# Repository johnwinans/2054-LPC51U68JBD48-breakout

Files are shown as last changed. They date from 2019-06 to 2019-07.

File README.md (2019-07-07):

# 2054-LPC51U68JBD48-breakout
LPC51U68JBD48 Breakout Board

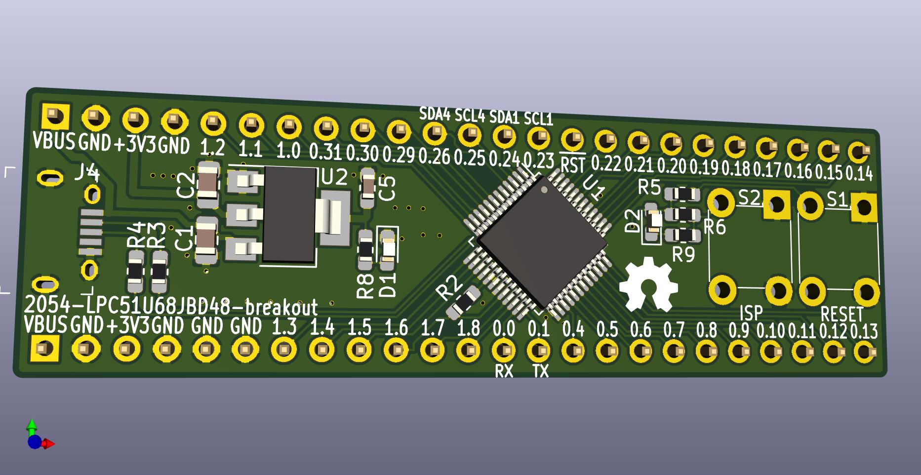
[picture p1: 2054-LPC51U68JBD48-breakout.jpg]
Front


Oops... I put the wrong URL on the Rev-1 release tag.  You can order Rev 1 of this board from OSH Park here: https://oshpark.com/shared_projects/a4fI5XNS (I receive no commission.)

Double-oops, there is no soldermask threaded between the pins of U1 in Rev-1.  This flaw is not a show-stopper.  It would have been nice to have.  

This has been fixed by reducing the solder mask expansion in Rev 1.1 to 1.8 mils.

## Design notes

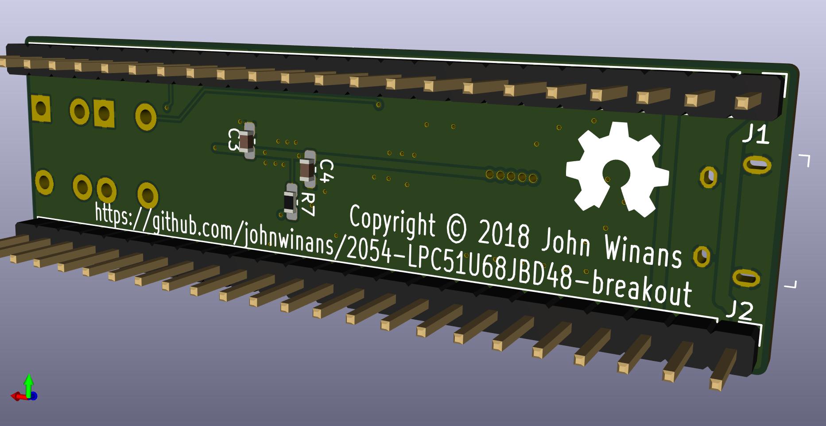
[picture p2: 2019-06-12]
2054-LPC51U68JBD48-breakout-back.jpg

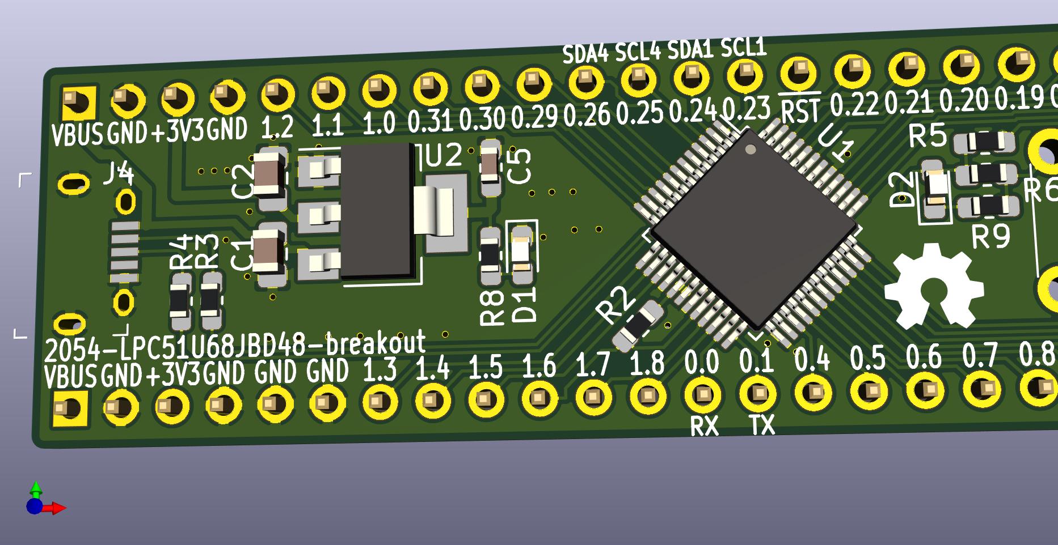
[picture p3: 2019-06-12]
2054-LPC51U68JBD48-breakout-back-front.jpg

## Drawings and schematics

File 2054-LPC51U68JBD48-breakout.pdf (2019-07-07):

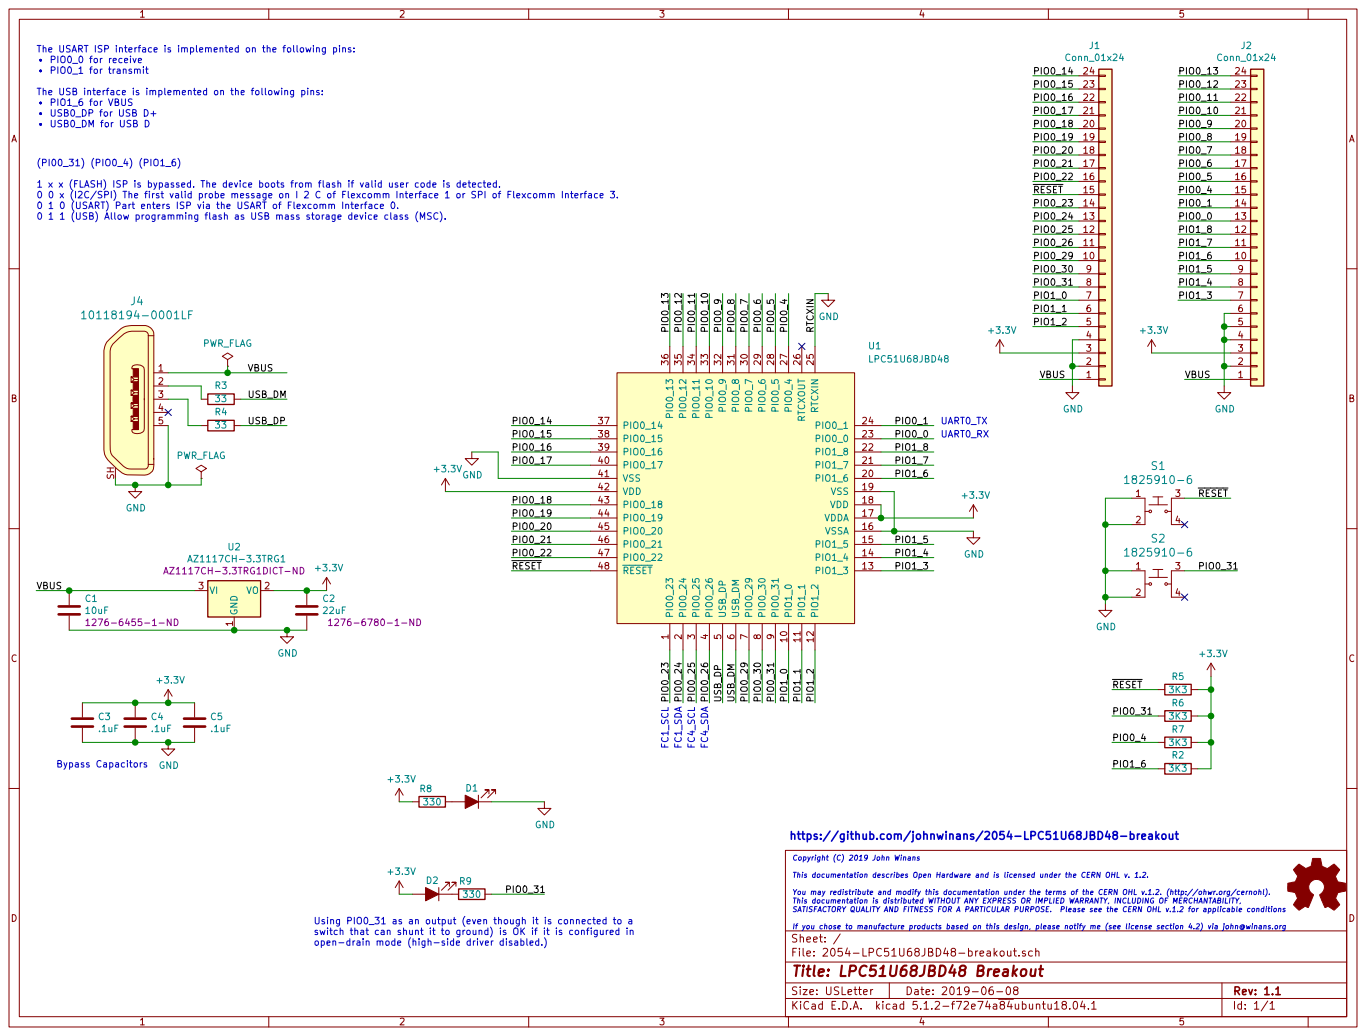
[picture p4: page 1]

The USART ISP interface is implemented on the following pins:
PIO0_0 for receive
PIO0_1 for transmit The USB interface is implemented on the following pins:

1 x x (FLASH) ISP is bypassed. The device boots from flash if valid user code is detected.
0 0 x (I2C/SPI) The first valid probe message on I 2 C of Flexcomm Interface 1 or SPI of Flexcomm Interface 3.
0 1 0 (USART) Part enters ISP via the USART of Flexcomm Interface 0.

1 PIO1_0 10 PIO1_1 11 PIO1_2 12 PIO1_3 13 PIO1_4 14 PIO1_5 15 VSSA 16 VDDA 17 VDD 18 VSS 19 PIO0_24

Copyright (C) 2019 John Winans This documentation describes Open Hardware and is licensed under the CERN OHL v. 1.2. You may redistribute and modify this documentation under the terms of the CERN OHL v.1.2. (http://ohwr.org/cernohl). This documentation is distributed WITHOUT ANY EXPRESS OR IMPLIED WARRANTY, INCLUDING OF MERCHANTABILITY, SATISFACTORY QUALITY AND FITNESS FOR A PARTICULAR PURPOSE. Please see the CERN OHL v.1.2 for applicable conditions

PIO0_31 Using PIO0_31 as an output (even though it is connected to a

If you chose to manufacture products based on this design, please notify me (see license section 4.2) via john@winans.org

switch that can shunt it to ground) is OK if it is configured in

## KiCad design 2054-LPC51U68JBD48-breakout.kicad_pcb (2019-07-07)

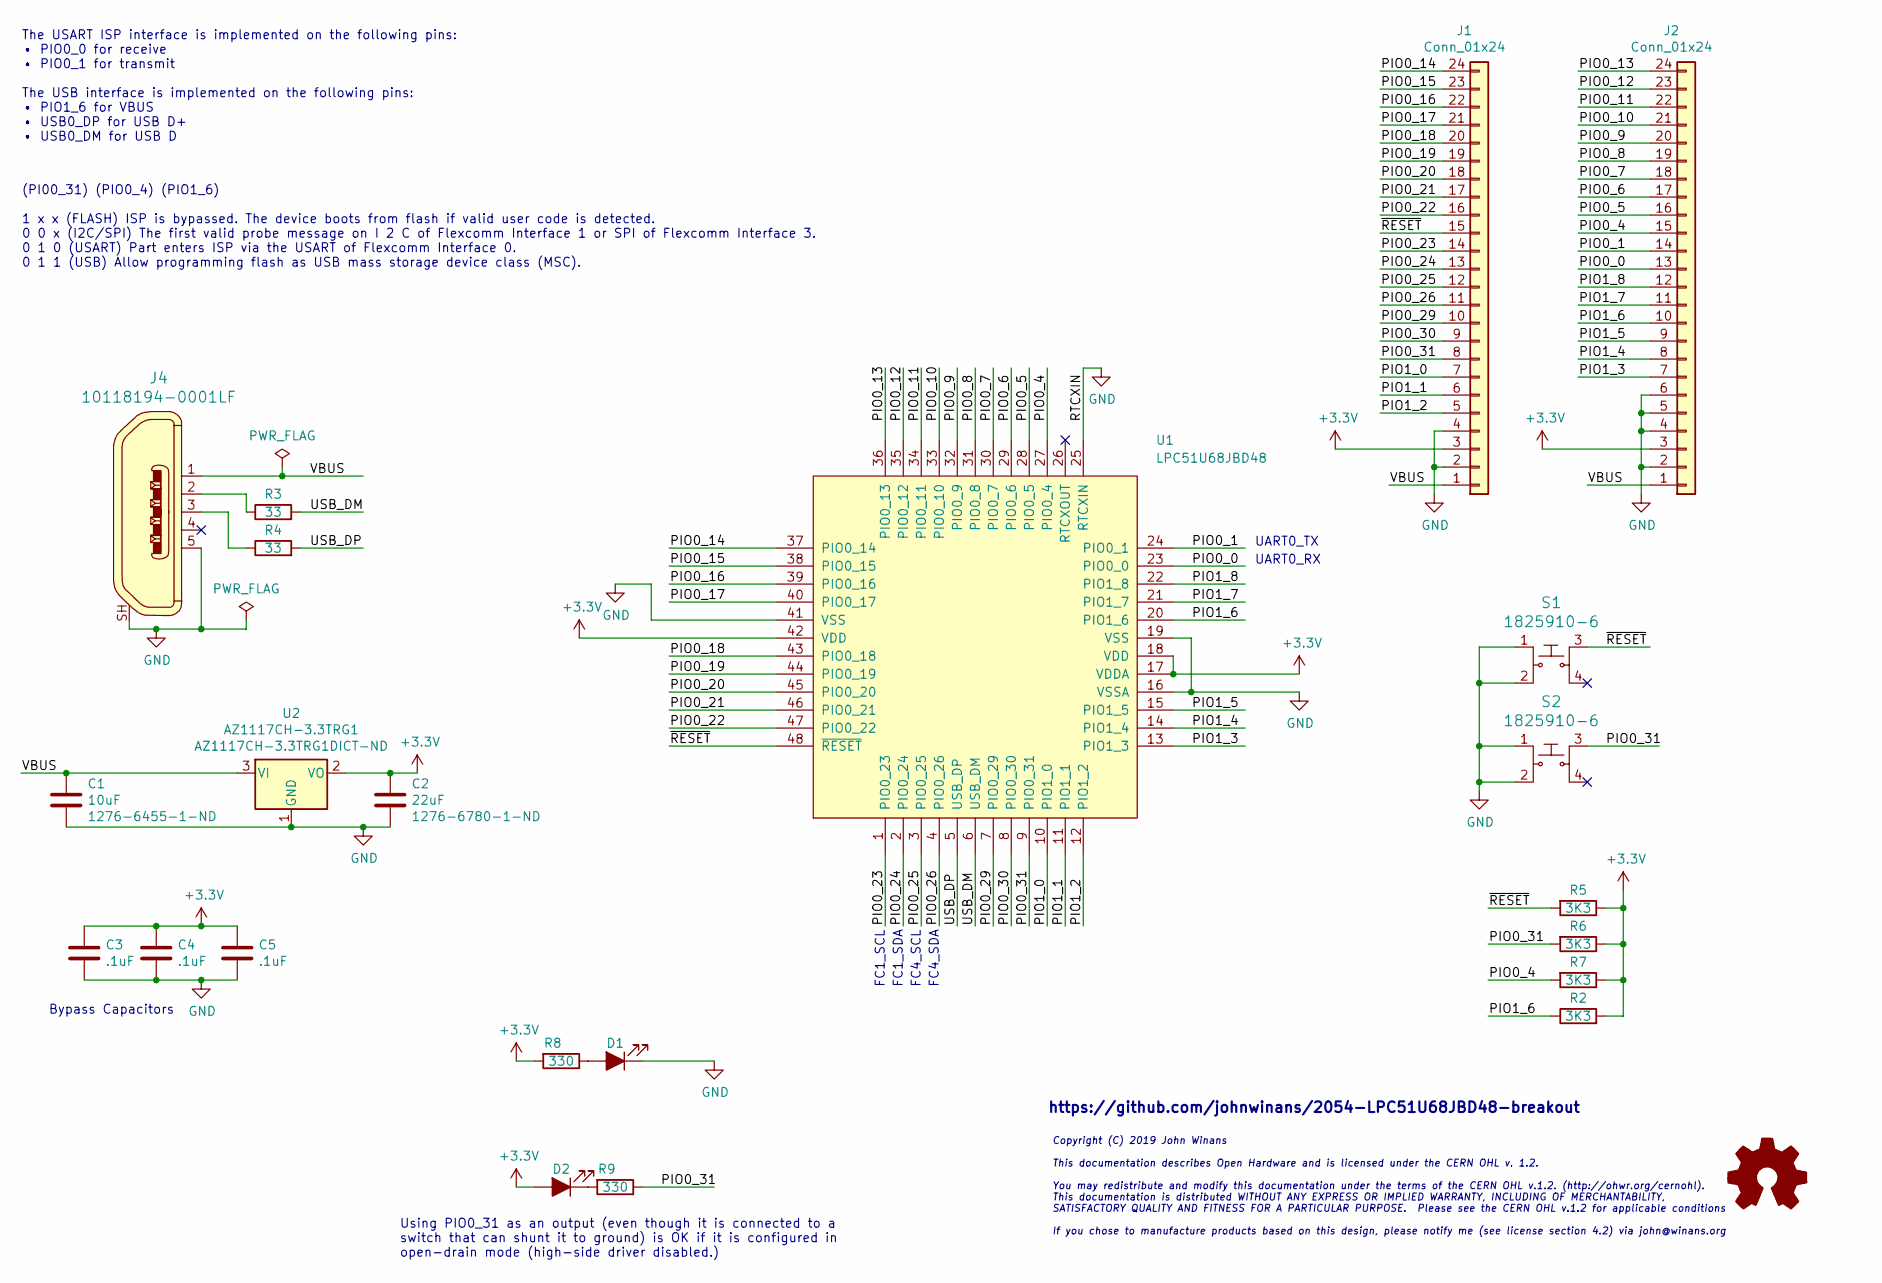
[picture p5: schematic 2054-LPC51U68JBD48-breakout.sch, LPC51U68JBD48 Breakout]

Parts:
C1: 10uF; C_0805_2012Metric_Pad1.15x1.40mm_HandSolder; digikey 1276-6455-1-ND
C2: 22uF; C_0805_2012Metric_Pad1.15x1.40mm_HandSolder; digikey 1276-6780-1-ND
C3, C4, C5: .1uF; C_0603_1608Metric_Pad1.05x0.95mm_HandSolder; digikey.com 445-6854-1-ND
D1, D2: LED_ALT; LED_0603_1608Metric_Pad1.05x0.95mm_HandSolder
J1, J2: Conn_01x24; PinHeader_1x24_P2.54mm_Vertical
J4: 10118194-0001LF; USB_Micro_B_Female_10118194-0001LF; MPN 10118194-0001LF; Digi-Key_PN 609-4618-1-ND
LOGO1: Logo_Open_Hardware_Small; OSHW-Symbol_6.7x6mm_SilkScreen
R2, R5, R6, R7: 3K3; R_0603_1608Metric_Pad1.05x0.95mm_HandSolder; digikey.com 311-100HRCT-ND
R3, R4: 33; R_0603_1608Metric_Pad1.05x0.95mm_HandSolder; digikey.com 311-100HRCT-ND
R8, R9: 330; R_0603_1608Metric_Pad1.05x0.95mm_HandSolder; digikey.com 311-1.00KHRCT-ND
S1, S2: 1825910-6; Switch_Tactile_THT_6x6mm; MPN 1825910-6; Digi-Key_PN 450-1650-ND
U1: LPC51U68JBD48; LQFP-48_7x7mm_P0.5mm
U2: AZ1117CH-3.3TRG1; SOT-223-3_TabPin2; digikey AZ1117CH-3.3TRG1DICT-ND

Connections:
+3V3: C2.1, C3.1, C4.1, C5.1, D2.2 (A), J1.3, J2.3, R2.2, R5.1, R6.1, R7.1, R8.2, U1.17 (VDDA), U1.18 (VDD), U1.42 (VDD), U2.2 (VO)
/PIO0_0: J2.13, U1.23 (PIO0_0)
/PIO0_1: J2.14, U1.24 (PIO0_1)
/PIO0_4: J2.15, R7.2, U1.27 (PIO0_4)
/PIO0_5: J2.16, U1.28 (PIO0_5)
/PIO0_6: J2.17, U1.29 (PIO0_6)
/PIO0_7: J2.18, U1.30 (PIO0_7)
/PIO0_8: J2.19, U1.31 (PIO0_8)
/PIO0_9: J2.20, U1.32 (PIO0_9)
/PIO0_10: J2.21, U1.33 (PIO0_10)
/PIO0_11: J2.22, U1.34 (PIO0_11)
/PIO0_12: J2.23, U1.35 (PIO0_12)
/PIO0_13: J2.24, U1.36 (PIO0_13)
/PIO0_14: J1.24, U1.37 (PIO0_14)
/PIO0_15: J1.23, U1.38 (PIO0_15)
/PIO0_16: J1.22, U1.39 (PIO0_16)
/PIO0_17: J1.21, U1.40 (PIO0_17)
/PIO0_18: J1.20, U1.43 (PIO0_18)
/PIO0_19: J1.19, U1.44 (PIO0_19)
/PIO0_20: J1.18, U1.45 (PIO0_20)
/PIO0_21: J1.17, U1.46 (PIO0_21)
/PIO0_22: J1.16, U1.47 (PIO0_22)
/PIO0_23: J1.14, U1.1 (PIO0_23)
/PIO0_24: J1.13, U1.2 (PIO0_24)
/PIO0_25: J1.12, U1.3 (PIO0_25)
/PIO0_26: J1.11, U1.4 (PIO0_26)
/PIO0_29: J1.10, U1.7 (PIO0_29)
/PIO0_30: J1.9, U1.8 (PIO0_30)
/PIO0_31: J1.8, R6.2, R9.1, S2.3, U1.9 (PIO0_31)
/PIO1_0: J1.7, U1.10 (PIO1_0)
/PIO1_1: J1.6, U1.11 (PIO1_1)
/PIO1_2: J1.5, U1.12 (PIO1_2)
/PIO1_3: J2.7, U1.13 (PIO1_3)
/PIO1_4: J2.8, U1.14 (PIO1_4)
/PIO1_5: J2.9, U1.15 (PIO1_5)
/PIO1_6: J2.10, R2.1, U1.20 (PIO1_6)
/PIO1_7: J2.11, U1.21 (PIO1_7)
/PIO1_8: J2.12, U1.22 (PIO1_8)
/USB_DM: R3.2, U1.6 (USB_DM)
/USB_DP: R4.2, U1.5 (USB_DP)
/VBUS: C1.1, J1.1, J2.1, J4.1, U2.3 (VI)
/~RESET~: J1.15, R5.2, S1.3, U1.48 (~RESET~)
GND: C1.2, C2.2, C3.2, C4.2, C5.2, D1.1 (K), J1.2, J1.4, J2.2, J2.4, J2.5, J2.6, J4.5, J4.SH, S1.1, S1.2, S2.1, S2.2, U1.16 (VSSA), U1.19 (VSS), U1.25 (RTCXIN), U1.41 (VSS), U2.1 (GND)
unnamed: D1.2 (A), R8.1
unnamed: D2.1 (K), R9.2
unnamed: J4.2, R3.1
unnamed: J4.3, R4.1

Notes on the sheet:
Bypass Capacitors
Copyright (C) 2019 John Winans This documentation describes Open Hardware and is licensed under the CERN OHL v. 1.2. You may redistribute and modify this documentation under the terms of the CERN OHL v.1.2. (http://ohwr.org/cernohl). This documentation is distributed WITHOUT ANY EXPRESS OR IMPLIED 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
The USART ISP interface is implemented on the following pins: • PIO0_0 for receive • PIO0_1 for transmit The USB interface is implemented on the following pins: • PIO1_6 for VBUS • USB0_DP for USB D+ • USB0_DM for USB D
(PI00_31) (PIO0_4) (PIO1_6) 1 x x (FLASH) ISP is bypassed. The device boots from flash if valid user code is detected. 0 0 x (I2C/SPI) The first valid probe message on I 2 C of Flexcomm Interface 1 or SPI of Flexcomm Interface 3. 0 1 0 (USART) Part enters ISP via the USART of Flexcomm Interface 0. 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
FC1_SCL
FC1_SDA
FC4_SCL
FC4_SDA
UART0_TX
UART0_RX
Using PIO0_31 as an output (even though it is connected to a switch that can shunt it to ground) is OK if it is configured in open-drain mode (high-side driver disabled.)
https://github.com/johnwinans/2054-LPC51U68JBD48-breakout

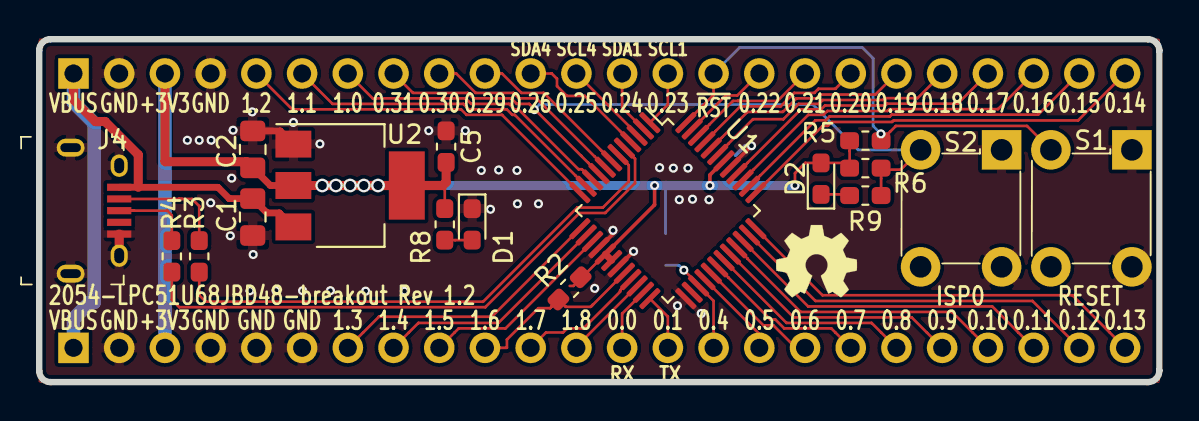
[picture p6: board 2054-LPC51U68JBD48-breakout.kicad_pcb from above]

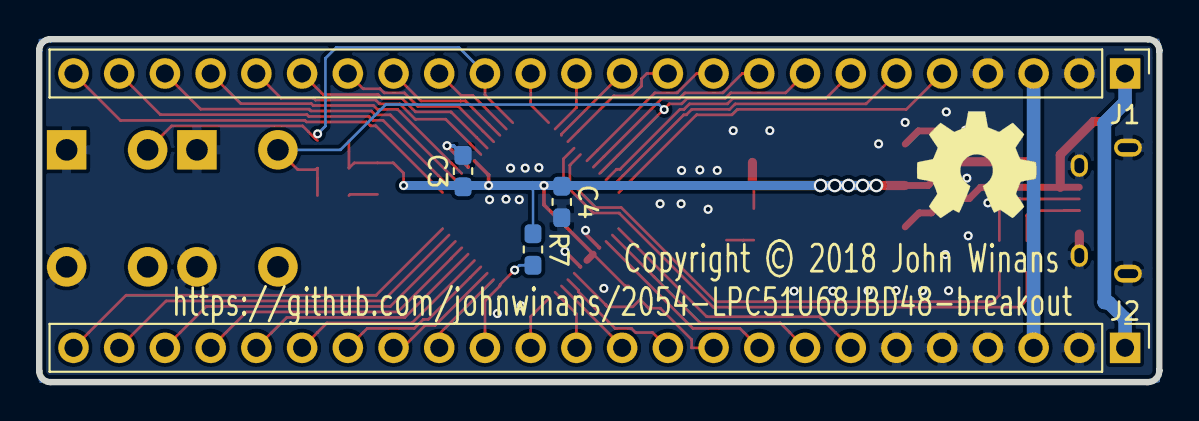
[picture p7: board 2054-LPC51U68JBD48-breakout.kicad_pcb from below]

Board: 2 copper layers, 62.2 x 19.0 mm, 23 parts (6 on the bottom side), 47 nets.

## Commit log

2019-06-12 Initial project import
    [2054-LPC51U68JBD48-breakout.kicad_pcb, 2054-LPC51U68JBD48-breakout.sch]
2019-06-23 Add note about the soldermask around U1 pins.
2019-06-23 Reduce soldermask expansion to 1.8mil
    [2054-LPC51U68JBD48-breakout.kicad_pcb, 2054-LPC51U68JBD48-breakout.sch]
2019-07-07 CHanged Rev number on schematic & PCB.
    [2054-LPC51U68JBD48-breakout.kicad_pcb, 2054-LPC51U68JBD48-breakout.sch]
2021-07-07 Added the cache.lib in case anyone needs it.

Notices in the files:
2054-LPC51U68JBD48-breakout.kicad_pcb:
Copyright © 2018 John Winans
